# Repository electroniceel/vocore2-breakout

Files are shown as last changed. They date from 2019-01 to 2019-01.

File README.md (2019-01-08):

Breakout board for VoCore2 CPU module
=====================================

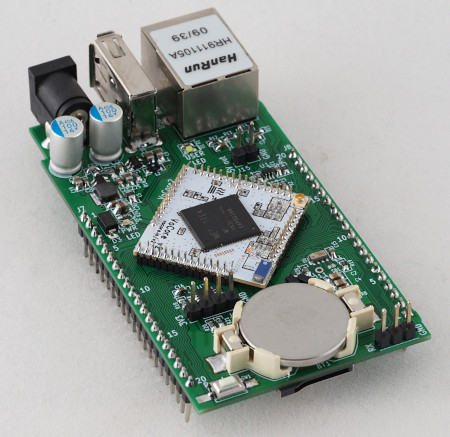
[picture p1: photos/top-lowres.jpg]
Top side
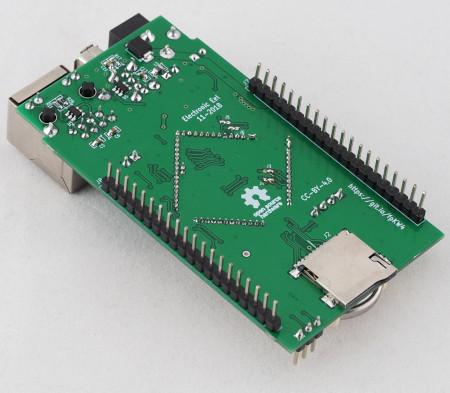
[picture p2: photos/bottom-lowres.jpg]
Bottom side
| [](https://github.com/electroniceel/vocore2-breakout/raw/master/photos/top-highres.jpg) | [](https://github.com/electroniceel/vocore2-breakout/raw/master/photos/bottom-highres.jpg) |

Main Features
-------------

- Uses a bare [VoCore2 CPU module](https://vocore.io/v2.html)
- core components on board
  - 1x RJ45 10/100 Ethernet
  - 1x USB-Host
  - 1x microSD
  - 12 VDC in with Buck-converter to 5V
  - RTC (MicroCrystal RV-8803-C7) and CR2032 battery
  - TCN75A or similar I2C temperature sensor
- Other pins broken out to 2.54mm pin headers (2x20)
- Separate pin headers for the console (UART2), protected by 74LVC2G17 buffer

Layout & Schematics
-------------------

See the ["kicad" directory](https://github.com/electroniceel/vocore2-breakout/tree/master/kicad).

There is also a [PDF version of the schematics](https://github.com/electroniceel/vocore2-breakout/raw/master/schematics.pdf) available.

Parts
-----

See the KiCad part data in the schematics and the linked footprints.

The only non-obvious part is the microSD socket. It is a common model found at Chinese suppliers.
The insertion/removal type is push-push (push-in, push-out).

It goes under various names and model numbers, often called "TF" or "TransFlash". Sometimes you
find more detailed numbers, like "TF09-2-12B" or "TF-01A".

You can get them from for example these offers:
- https://lcsc.com/product-detail/Connector-Card-Sockets_Korean-Hroparts-Elec-TF-01A_C91145.html
- https://www.aliexpress.com/item//32603008211.html
- https://www.aliexpress.com/item//32637213532.html

No warranties for correctness of these offers.

Solderbridges
-------------

The board contains two sets of solderbridges to select between features:

#### J3 & J4

You can select to which I2C bus to connect the onboard I2C components like RTC and temperature sensor.

You can select between 
1. the hardware I2C of the MT76x8, pins I2C_SD and I2C_CLK
2. a software emulated I2C bus on GPIO39 and GPIO40, using the driver i2c-gpio

#### J5 & J6

Select if you want the USB bus on the USB-A-Socket at the edge of the board or on the pin headers.
The USB bus shouldn't be connected to both because of reflections on the stub traces.

OpenWRT patches
---------------

- OpenWRT upstream already contains support for the VoCore2
- But the Device Tree there is a bit "sparse" and some features are disabled
- So I have created a new Target Profile called "VoCore2-Breakout" and some small adaptions to make the features work
- You can find this work in the ["openwrt" directory](https://github.com/electroniceel/vocore2-breakout/tree/master/openwrt)
- Use either the 0003a- or 0003b- patch based on how the solderbridges J3 & J4 are set

To use these:
1. First prepare the OpenWRT build system as described in https://openwrt.org/docs/guide-developer/build-system/start
2. Apply my patches before running "make menuconfig"
3. Select Target "MediaTek Ralink MIPS", Subtarget "MT76x8 based boards", Target Profile "VoCore2-Breakout"
4. Build

License
-------


This work is licensed under a [Creative Commons Attribution 4.0 International License](https://creativecommons.org/licenses/by/4.0/).

Please link to https://git.io/fpKW4 for attribution.

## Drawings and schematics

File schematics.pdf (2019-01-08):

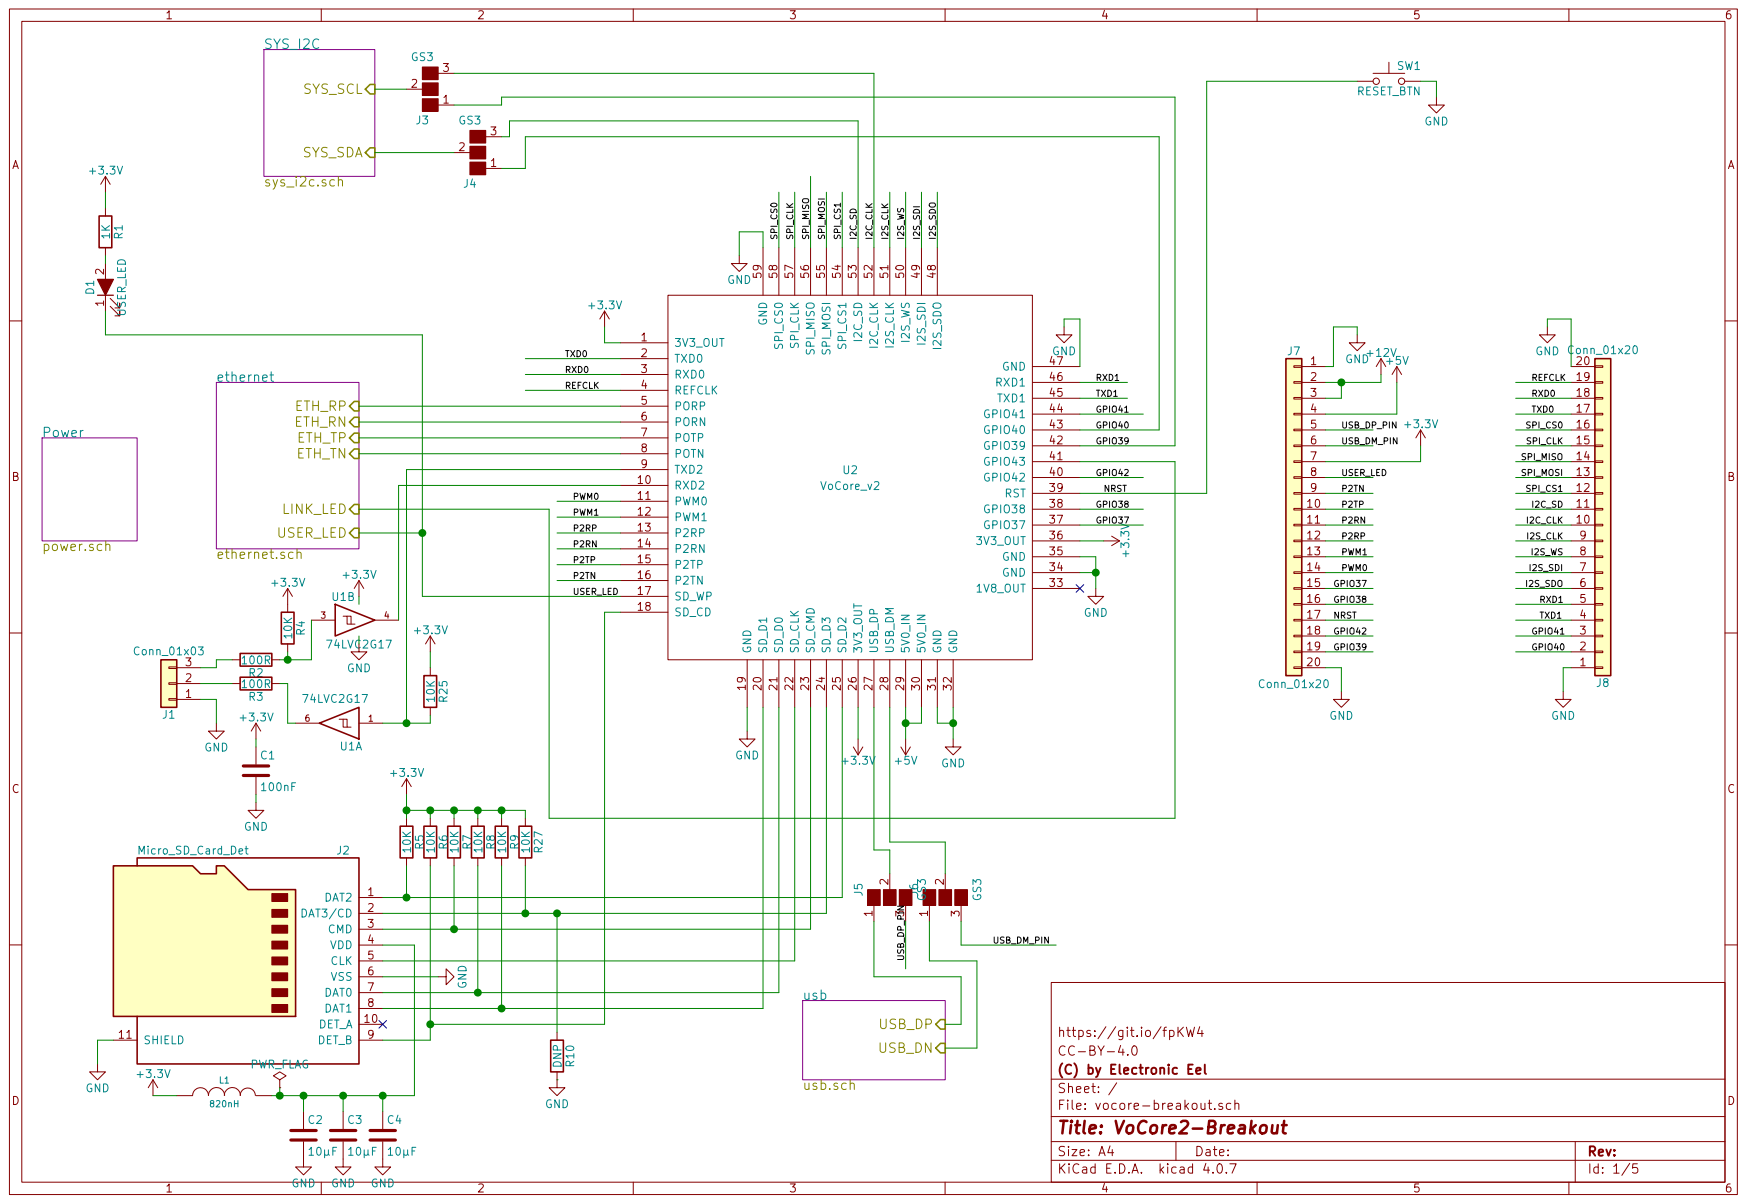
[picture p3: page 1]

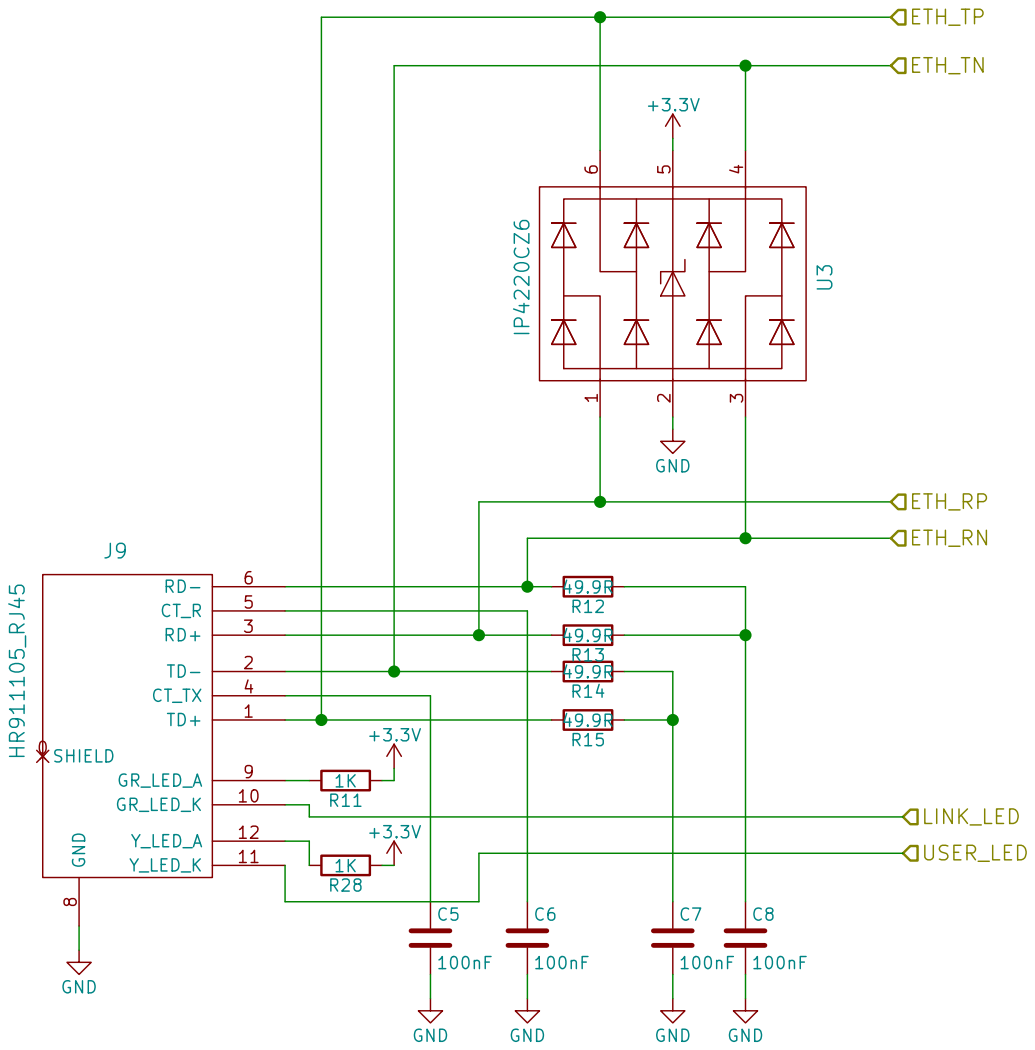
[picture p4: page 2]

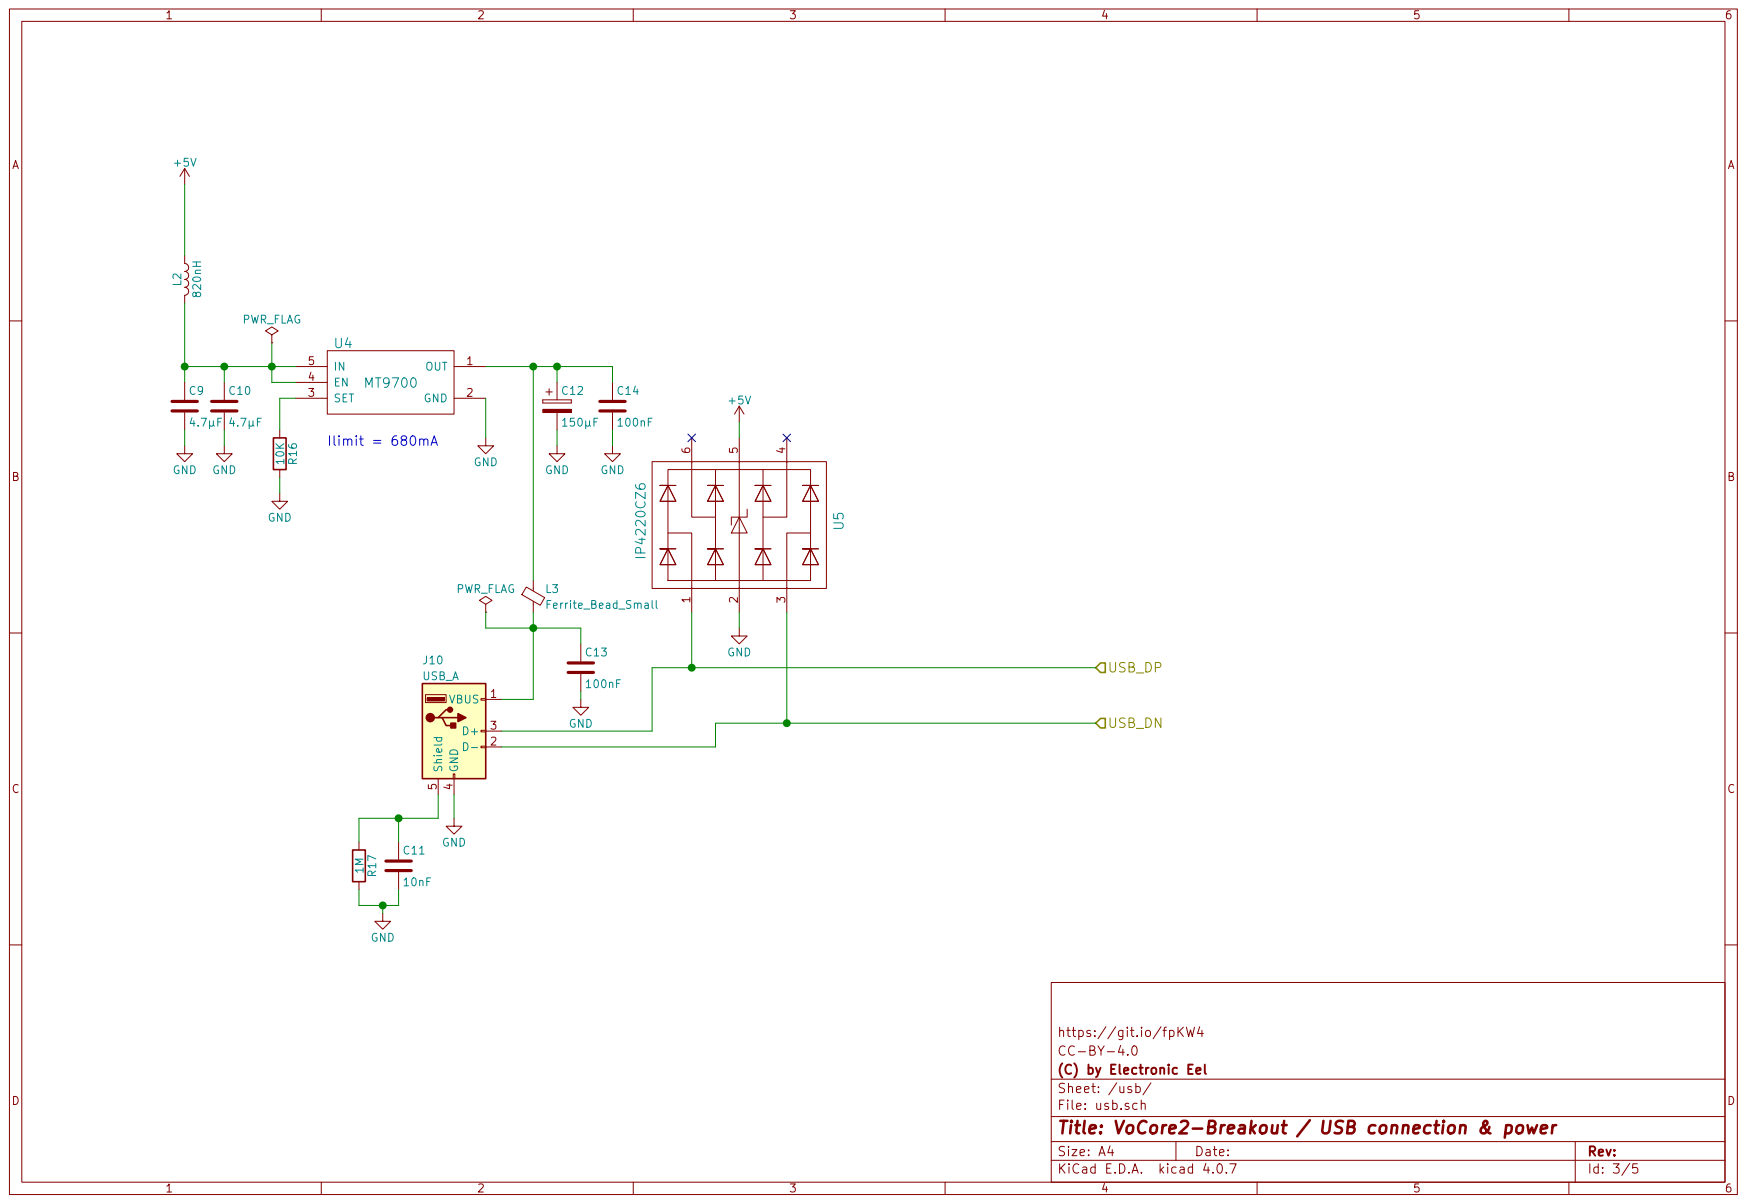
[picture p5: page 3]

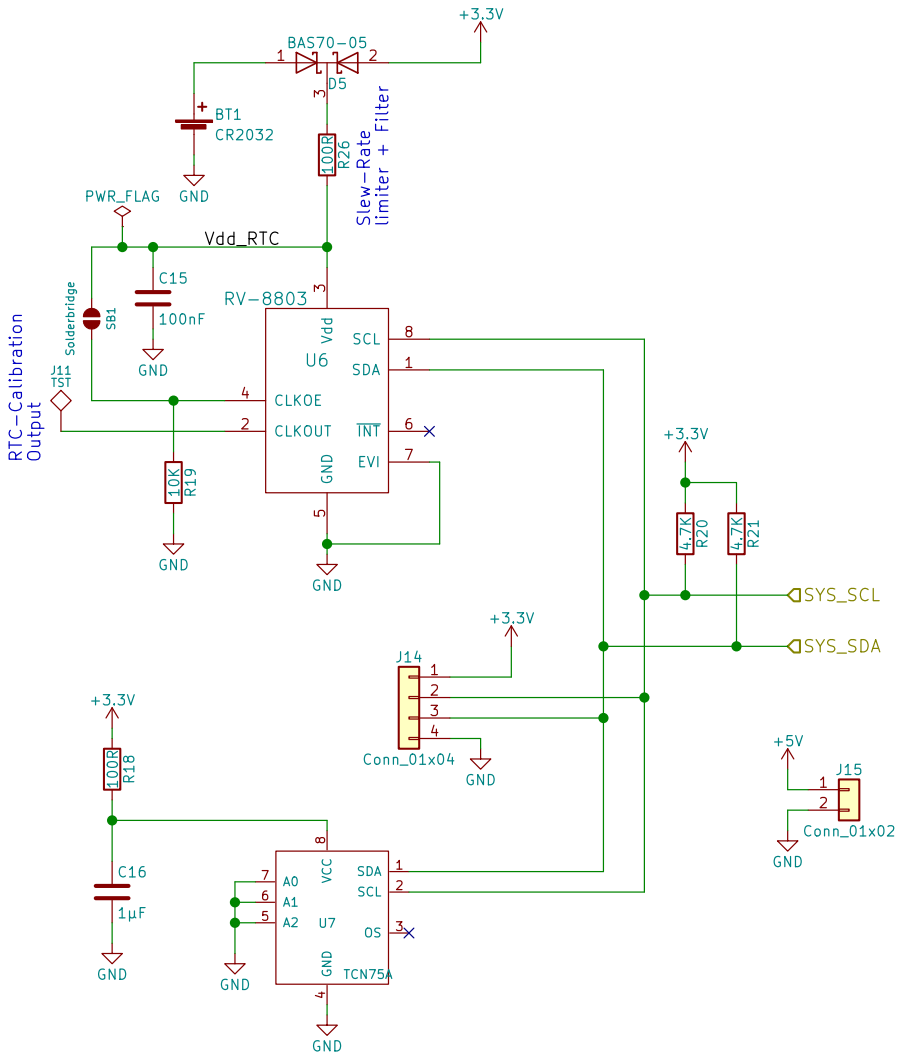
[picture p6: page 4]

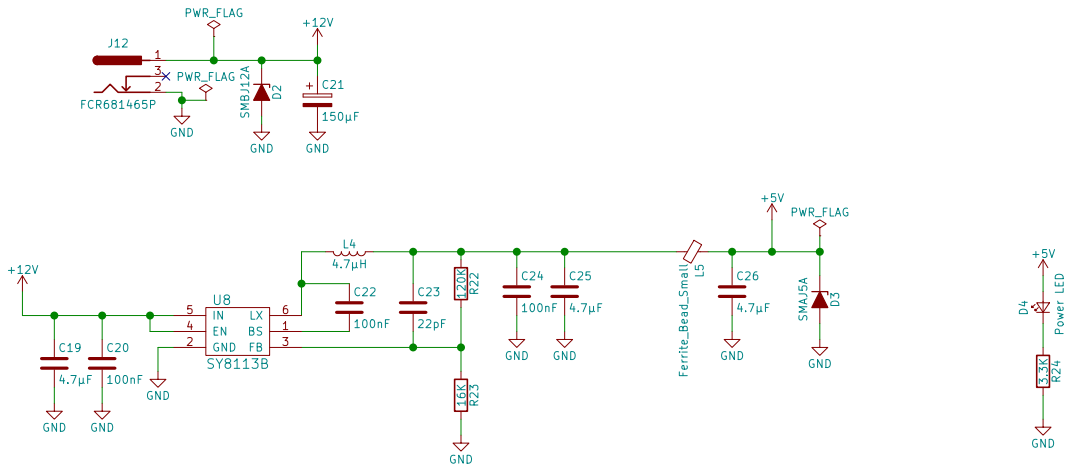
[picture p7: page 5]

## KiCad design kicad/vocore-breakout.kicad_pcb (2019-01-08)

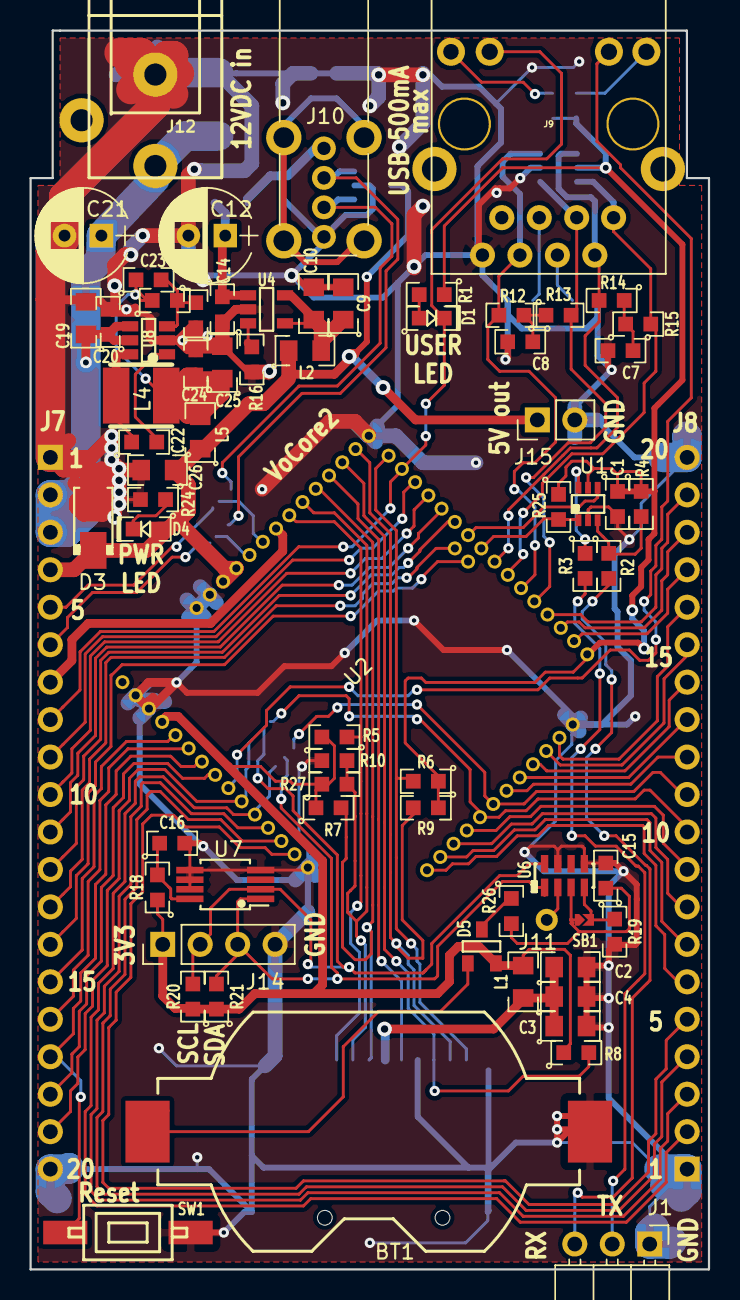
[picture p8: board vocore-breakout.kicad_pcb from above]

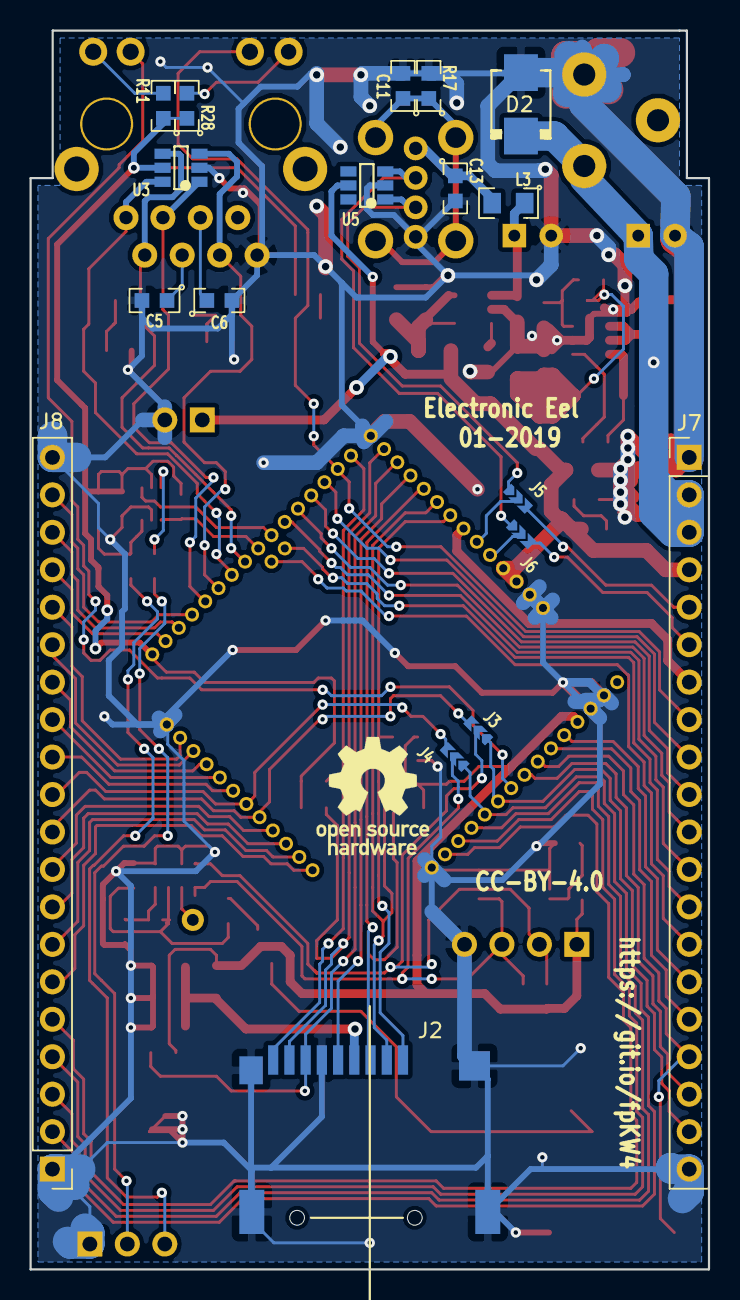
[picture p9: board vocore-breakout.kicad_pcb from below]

Board: 2 copper layers, 46.0 x 84.0 mm, 87 parts (18 on the bottom side), 84 nets.

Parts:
BT1: CR2032; SMTU2032-LF-CoinCell
C1, C5, C6, C7, C8, C13, C14, C15, C20, C22, C24: 100nF; SMD0603-wide-C
C2, C3, C4: 10µF; SMD0805-wide-C
C9, C10, C19, C25, C26: 4.7µF; SMD0805-wide-C
C11: 10nF; SMD0603-wide-C
C12, C21: 150µF; CP_Radial_D6.3mm_P2.50mm
C16: 1µF; SMD0603-wide-C
C23: 22pF; SMD0603-wide-C
D1: USER_LED; SMD0603-wide-diode
D2: SMBJ12A; SMB_Diode
D3: SMAJ5A; SMA_Diode
D4: Power LED; SMD0603-wide-diode
D5: BAS70-05; SOT-23
J1: Conn_01x03; Pin_Header_Angled_1x03_Pitch2.54mm
J2: Micro_SD_Card_Det; microSD-Receptacle-SelfEject
J3, J4, J5, J6: GS3; Solderbridge-3pad
J7, J8: Conn_01x20; Pin_Header_Straight_1x20_Pitch2.54mm
J9: HR911105_RJ45; RJ45-HR911105A
J10: USB_A; USB_A_Vertical_THT
J11: TST; Measurement_Point_Round-TH_Small
J12: Barrel_Jack; Cliff_FCR681465P_barrel_jack
J14: Conn_01x04; Pin_Header_Straight_1x04_Pitch2.54mm
J15: Conn_01x02; Pin_Header_Straight_1x02_Pitch2.54mm
L1, L2: 820nH; SMD0805-wide
L3, L5: Ferrite_Bead_Small; SMD0805-wide
L4: 4.7µH; Fastron-1616FPS
R1, R11, R28: 1K; SMD0603-wide-R
R2, R3, R18, R26: 100R; SMD0603-wide-R
R4, R5, R6, R7, R8, R9, R16, R19, R25, R27: 10K; SMD0603-wide-R
R10: DNP; SMD0603-wide-R
R12, R13, R14, R15: 49.9R; SMD0603-wide-R
R17: 1M; SMD0603-wide-R
R20, R21: 4.7K; SMD0603-wide-R
R22: 120K; SMD0603-wide-R
R23: 16K; SMD0603-wide-R
R24: 3.3K; SMD0603-wide-R
SB1: Solderbridge
SW1: RESET_BTN; Push-Button-SMD-6.0x3.5mm
U1: 74LVC2G17; SC-70-6-wide
U2: VoCore_v2
U3, U5: IP4220CZ6; SOT-23-6
U4: MT9700; SOT-23-5
U6: RV-8803; MicroCrystal-C7
U7: MCP9808; MSOP-8-wide
U8: SY8113B; SOT-23-6

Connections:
+3V3: C1.1, D5.2, J7.7, J14.1, L1.2, R1.1, R4.1, R5.1, R6.1, R7.1, R8.1, R9.1, R11.1, R18.1, R20.1, R21.1, R25.1, R27.1, R28.1, U1.5, U2.1, U2.26, U2.36, U3.5
+5V: C26.1, D3.1, D4.2, J7.4, J15.1, L2.1, L5.1, U2.29, U2.30, U5.5
+12V: C19.1, C20.1, C21.1, D2.1, J7.2, J7.3, J12.1, U8.4, U8.5
/GPIO37: J7.15, U2.37
/GPIO38: J7.16, U2.38
/GPIO39: J3.1, J7.19, U2.42
/GPIO40: J4.1, J8.2, U2.43
/GPIO41: J8.3, U2.44
/GPIO42: J7.18, U2.40
/I2C_CLK: J3.3, J8.10, U2.52
/I2C_SD: J4.3, J8.11, U2.53
/I2S_CLK: J8.9, U2.51
/I2S_SDI: J8.7, U2.49
/I2S_SDO: J8.6, U2.48
/I2S_WS: J8.8, U2.50
/NRST: J7.17, SW1.1, U2.39
/P2RN: J7.11, U2.14
/P2RP: J7.12, U2.13
/P2TN: J7.9, U2.16
/P2TP: J7.10, U2.15
/PWM0: J7.14, U2.11
/PWM1: J7.13, U2.12
/REFCLK: J8.19, U2.4
/RXD0: J8.18, U2.3
/RXD1: J8.5, U2.46
/SPI_CLK: J8.15, U2.57
/SPI_CS0: J8.16, U2.58
/SPI_CS1: J8.12, U2.54
/SPI_MISO: J8.14, U2.56
/SPI_MOSI: J8.13, U2.55
/SYS_I2C/SYS_SCL: J3.2, J14.2, R20.2, U6.8, U7.2
/SYS_I2C/SYS_SDA: J4.2, J14.3, R21.2, U6.1, U7.1
/SYS_I2C/Vdd_RTC: C15.1, R26.2, SB1.1, U6.3
/TXD0: J8.17, U2.2
/TXD1: J8.4, U2.45
/USB_DM_PIN: J6.3, J7.6
/USB_DP_PIN: J5.3, J7.5
/USER_LED: D1.1, J7.8, J9.11, U2.17
/ethernet/ETH_RN: J9.6, R12.2, U2.6, U3.3
/ethernet/ETH_RP: J9.3, R13.2, U2.5, U3.1
/ethernet/ETH_TN: J9.2, R14.2, U2.8, U3.4
/ethernet/ETH_TP: J9.1, R15.2, U2.7, U3.6
/ethernet/LINK_LED: J9.10, U2.41
/usb/USB_DN: J6.1, J10.2, U5.3
/usb/USB_DP: J5.1, J10.3, U5.1
GND: BT1.2, C1.2, C2.2, C3.2, C4.2, C5.2, C6.2, C7.2, C8.2, C9.2, C10.2, C11.2, C12.2, C13.2, C14.2, C15.2, C16.2, C19.2, C20.2, C21.2, C24.2, C25.2, C26.2, D2.2, D3.2, J1.1, J2.6, J2.11, J7.1, J7.20, J8.1, J8.20, J9.8, J10.4, J12.2, J14.4, J15.2, R10.2, R16.2, R17.2, R19.2, R23.2, R24.2, SW1.2, U1.2, U2.19, U2.31, U2.32, U2.34, U2.35, U2.47, U2.59, U3.2, U4.2, U5.2, U6.5, U6.7, U7.4, U7.5, U7.6, U7.7, U8.2
unnamed: BT1.1, D5.1
unnamed: C2.1, C3.1, C4.1, J2.4, L1.1
unnamed: C5.1, J9.4
unnamed: C6.1, J9.5
unnamed: C7.1, R14.1, R15.1
unnamed: C8.1, R12.1, R13.1
unnamed: C9.1, C10.1, L2.2, U4.4, U4.5
unnamed: C11.1, J10.5, R17.1
unnamed: C12.1, C14.1, L3.1, U4.1
unnamed: C13.1, J10.1, L3.2
unnamed: C16.1, R18.2, U7.8
unnamed: C22.1, L4.2, U8.6
unnamed: C22.2, U8.1
unnamed: C23.1, C24.1, C25.1, L4.1, L5.2, R22.1
unnamed: C23.2, R22.2, R23.1, U8.3
unnamed: D1.2, R1.2
unnamed: D4.1, R24.1
unnamed: D5.3, R26.1
unnamed: J1.2, R3.2
unnamed: J1.3, R2.2
unnamed: J2.1, R5.2, U2.25
unnamed: J2.2, R10.1, R27.2, U2.24
unnamed: J2.3, R7.2, U2.23
unnamed: J2.5, U2.22
unnamed: J2.7, R8.2, U2.21
unnamed: J2.8, R9.2, U2.20
unnamed: J2.9, R6.2, U2.18
unnamed: J5.2, U2.27
unnamed: J6.2, U2.28
unnamed: J9.9, R11.2
unnamed: J9.12, R28.2
unnamed: J11.1, U6.2
unnamed: R2.1, R4.2, U1.3
unnamed: R3.1, U1.6
unnamed: R16.1, U4.3
unnamed: R19.1, SB1.2, U6.4
unnamed: R25.2, U1.1, U2.9
unnamed: U1.4, U2.10

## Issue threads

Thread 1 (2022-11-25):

Can I buy this board

nsmith1024, 2022-11-25:
Hello,

Im wondering if its possible for me to buy this board completely soldered with all the part on it.

Please let me know I want to buy some of them

Thanks

electroniceel, 2022-11-25:
Thanks for your interest.

Unfortunately it is not easy to make a business out of selling boards like these. Also I don't want to deal with registering a company and all the bureaucracy like taxes that comes with it. And selling goods without that is illegal here.

Several vendors made PCB-Assembly services available for prototype and small quantity production recently. One such example is JLCPCB in China, the other AISLER in Germany. I have used the PCBA service from JLCPCB and it works well. You could have everything populated there except the Vocore itself. But that isn't too hard do solder onto the board when using 1.27mm pitch pin headers.

Closed 2022-11-25.

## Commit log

2019-01-08 import kicad project
    [ethernet.sch, power.sch, sys_i2c.sch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]
2019-03-24 add ready-to-order gerbers

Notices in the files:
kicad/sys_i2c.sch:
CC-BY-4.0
